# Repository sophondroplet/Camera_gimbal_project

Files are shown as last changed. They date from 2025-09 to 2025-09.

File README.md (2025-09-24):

## Camera Gimbal Project

This repository contains the mechanical CAD, drawings and embedded firmware for a small 2-axis/3-phase BLDC camera gimbal prototype. The project uses an STM32G431 MCU to read an MPU6050 IMU, an AS5048A-style PWM encoder input for rotor position, and drives a 3-phase BLDC (FOC-style) motor using TIM1 complementary PWM outputs.

Folders
- `CAD_files/` – STEP files and drawings for the 3D printed / machined parts and full assembly.
- `assets/` – photos, renders and PCB images used in documentation.
- `Software/STM32G431CUB6_firmware/` – STM32CubeIDE / Makefile firmware project. Contains HAL drivers, MPU6050 code, motor control and UART interface.
- `Software/UART_music_streamer/` – host-side Python utility (`music_streamer.py`) to convert MIDI files or a test scale to motor frequency/torque commands and stream them to the MCU over serial.

High level behaviour
- The MCU reads orientation (roll/pitch/yaw) from the MPU6050 via I2C using DMA.
- An absolute rotor position source (AS5048A PWM-style duty encoder) is read using TIM input capture on `TIM2`.
- A simple PID computes a torque command to follow the IMU-derived pitch setpoint; torque/d (direct/quadrature frame) are converted to 3-phase PWM using inverse Park/Clarke then written to `TIM1` CCR registers.
- UART is used for tuning PID gains at runtime by sending ASCII `P,D\n` lines (see firmware README). Additionally, the host audio streamer sends `FREQ/AMP` lines to play music on the motor (see `Software/UART_music_streamer/README.md`).

Quick start (recommended)
1. Install STM32CubeIDE (recommended) and the STM32G4 device support package.
2. Open the firmware project: `Software/STM32G431CUB6_firmware/gorgon test.ioc` or open the project workspace in STM32CubeIDE.
3. Build the project (Project → Build). Connect an ST-Link and flash using the IDE or STM32CubeProgrammer.

Command-line build & flash (advanced)
- This project contains generated makefiles in the `Debug/` folder. You can build with an ARM GNU toolchain (arm-none-eabi + make). Example (PowerShell):

```powershell
cd .\Software\STM32G431CUB6_firmware\Debug
make all
```

- For flashing, use STM32CubeProgrammer (GUI) or the CLI: point it at the produced ELF/BIN in `Debug/`.

UART protocols in this repo
- PID tuning: send ASCII `P,D\n` lines (example `0.5,0.01\n`) — original firmware parsing behaviour.
- Motor audio streaming: `music_streamer.py` sends `FREQ:<Hz>,AMP:<0..1>\n` lines (example `FREQ:440.00,AMP:0.150\n`). The firmware must be updated to accept `FREQ/AMP` lines or a host proxy must translate them.

Safety and notes
- This firmware drives a BLDC motor. Only connect power and the motor after you have verified wiring and the gate driver. Use low gain values for initial tests and keep motor disconnected while verifying encoder/IMU readings.
- The firmware contains HAL drivers (STM32 HAL and CMSIS). See `Software/STM32G431CUB6_firmware/Drivers/` for license files (Apache/BSD as appropriate).

Resources and where to look next
- Firmware source: `Software/STM32G431CUB6_firmware/Core/Src` and `Core/Inc`.
- IMU code: `MPU6050.c`, `MPU6050_D.c` and headers.
- Motor/FOC code & PID: `main.c`, `music.c`, and the BLDC conversion helpers.
- Host audio streamer: `Software/UART_music_streamer/music_streamer.py` and this folder's README.

If you want, I can also:
- Add the small MCU-side parser for `FREQ/AMP` and a conservative mapping to `TIM6` prescaler or `torque` so `music_streamer.py` works out-of-the-box.
- Populate inline documentation in key source files or add a LICENSE and CONTRIBUTING guide.

License
- The repository contains third-party code (STM32Cube HAL, CMSIS) under their respective license texts included in `Software/STM32G431CUB6_firmware/Drivers/`. The project code inside `Core/` is provided AS-IS unless you tell me otherwise; add or edit a LICENSE file if you want an explicit project license.

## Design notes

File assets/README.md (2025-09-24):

Assets (images)
================

This folder contains photos and renders of the camera gimbal and PCB images used in documentation and presentations. Filenames are prefixed with `cag` and include photos of the build, PCB layouts and CAD screenshots.

Typical use
- Use these images in the main README or in reports/presentations.
- High-resolution images can be opened in any image viewer. Some files are PNG (CAD renders), others are JPG (photos).

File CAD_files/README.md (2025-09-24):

CAD files and drawings
======================

This folder contains STEP (3D CAD) files and drawings for the camera gimbal assembly.

Contents
- `3d_model/` — STEP files for each major part (connectors, top motor jig, TPU vibration damp rubber, and the full assembly). These can be opened in CAD tools such as FreeCAD, Fusion360 or SolidWorks.
- `drawings/Camera_gimbal_drawing.pdf` — a printable drawing with dimensions and assembly notes.

Usage
- Open STEP files in your preferred CAD package. For FreeCAD, use File → Open and select `.step` files. For Fusion360, import the STEP.
- Use `Camera_gimbal_drawing.pdf` for measurements, mounting hole locations and BOM references.

Notes
- STEP files may contain multiple solids and named parts. Export single-part STLs if you need to 3D print components.

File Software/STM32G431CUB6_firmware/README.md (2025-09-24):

STM32G431CUB6 Firmware
======================

This folder contains an STM32CubeIDE project (Gorgon test) which implements motor control and IMU-based stabilization for the camera gimbal prototype. The project targets an STM32G431CBU6 microcontroller and uses HAL drivers with some custom code for the MPU6050 and motor output.

What it implements
- MPU6050 IMU driver (I2C, DMA read) with simple complementary filter fusion (see `Core/Src/MPU6050.c` and `MPU6050_D.c`).
- PWM encoder reading using TIM2 input capture to measure duty cycle and derive absolute rotor angle (used like an AS5048A PWM output).
- Simple PID controller on pitch/angle that computes a torque command which is converted to 3-phase PWM values using inverse Park/Clarke (`main.c`).
- UART-based live PID tuning via ASCII `P,D\n` commands (existing behaviour).
- Optional host-driven audio: the host `music_streamer.py` can stream `FREQ/AMP` commands to the MCU to play music on the motor (see `Software/UART_music_streamer/` README for host-side details). The firmware must accept `FREQ:...,AMP:...` lines or you must add a small parser to convert these commands into internal variables.
- Small music/tone generator that toggles torque with `TIM6` to play notes (see `Core/Inc/music.h` and `Core/Src/music.c`).

Wiring (conceptual)
- Power: motor driver/gate driver and MCU power rails. Ensure correct supply voltages and common grounds.
- TIM1 PWM outputs (CH1/CH2/CH3 and complementary pins) go to the motor driver inputs. Confirm pin mapping in `mx` generated init code.
- TIM2 CH1 (rising capture) and CH2 (falling capture) read the PWM-encoded rotor position (device that outputs PWM duty proportional to angle, typically AS5048A in PWM mode).
- MPU6050: I2C SDA/SCL to `I2C1` pins, interrupt pin to `IMU_INT` GPIO (used to detect data ready). Pull-ups as required.
- UART: USART2 TX/RX used for debug and PID tuning. Connect to USB-serial or ST-Link VCP.

Build & flash
- Recommended: Open the project in STM32CubeIDE (the `.ioc` file is in the folder) and use the IDE to build/flash.
- Command-line: there are makefiles in `Debug/`. Use an ARM GCC toolchain compatible with the flags in the makefile (arm-none-eabi-gcc, make). Example (PowerShell):

```powershell
cd .\Software\STM32G431CUB6_firmware\Debug
make all
```

- The resulting ELF/BIN will be under `Debug/` and can be flashed with STM32CubeProgrammer or the IDE.

Runtime / Tuning
- By default the firmware listens on USART2 for ASCII lines ending in `\n`.
- Send `P,D\n` where `P` and `D` are floating point numbers (no spaces required). Example: `0.5,0.02\n`.
- The firmware echoes the received string and updates the running P and D gains immediately.
- To support `music_streamer.py` you can add a small `FREQ/AMP` parser (see the UART_music_streamer README for a suggested parsing approach). The parsed frequency and amplitude should be safely clamped in firmware before use.

Calibration and safety checklist
- Start with motors disconnected or use a bench load.
- Verify IMU readings first: with motor power off, observe UART debug prints (if enabled) for pitch/roll/yaw values.
- Verify encoder input: check TIM capture values and derived `angle` (look for a 0..2*pi range mapping).
- Use small `P` gains initially and confirm the movement direction is correct.
- Implement emergency stop or physical kill switch before powering motors under load.

Files of interest
- `Core/Inc` – headers for project variables and constants.
- `Core/Src/main.c` – main loop, PID and motor output conversions.
- `Core/Src/MPU6050.c`, `MPU6050_D.c` – IMU drivers.
- `Core/Inc/music.h`, `Core/Src/music.c` – simple tone generator used for debugging.

Licenses
- STM32 HAL and CMSIS code under their included licenses (see `Drivers/`).

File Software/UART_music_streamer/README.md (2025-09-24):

UART Music Streamer
===================

This folder contains `music_streamer.py`, a host-side utility that converts MIDI files (or simple test scales) into realtime motor frequency/torque commands and streams them to the STM32 firmware over a serial link.

What the script does
- Parses MIDI files using `mido` and converts note_on/note_off events into a time-series of (frequency, amplitude) samples.
- Streams those samples at a configurable sample rate to the MCU using an ASCII protocol: `FREQ:<frequency>,AMP:<amplitude>\n` (example: `FREQ:440.00,AMP:0.150\n`).
- Provides a `--scale` test mode to play a C major scale for quick hardware verification.

Dependencies
- Python 3.8+
- pyserial
- mido
- numpy

Install (Windows PowerShell example):

```powershell
python -m pip install --user pyserial mido numpy
```

Usage
- Play a MIDI file over serial:

```powershell
python .\music_streamer.py --port COM3 --baud 115200 path\to\file.mid
```

- Play a test scale:

```powershell
python .\music_streamer.py --port COM3 --baud 115200 --scale
```

Serial protocol emitted by the script
- ASCII line per sample terminated with `\n`.
- Format: `FREQ:<frequency_Hz>,AMP:<amplitude_0_to_1>\n`
- Example: `FREQ:440.00,AMP:0.150\n`

Compatibility and firmware notes
- The `music_streamer.py` script sends `FREQ/AMP` command lines. The firmware in `Software/STM32G431CUB6_firmware` originally parsed `P,D\n` for PID tuning. To use `music_streamer.py` directly you must run firmware that accepts `FREQ/AMP` lines or add a small firmware parser that maps frequency/amplitude to the motor control variables.

Suggested minimal firmware parsing approach
1) Add globals to share the host command (example in a new header `Core/Inc/music_cmd.h`):

```c
// Example globals
extern float host_command_frequency_hz; // Hz
extern float host_command_amplitude;    // 0..1
extern volatile uint8_t host_command_new; // flag set when new command arrives
```

2) In your UART handler (or a small command processing task) parse `FREQ:` lines. Example pseudocode for a simple parser:

```c
void process_serial_line(char *line){
    float f = 0.0f, a = 0.0f;
    if (sscanf(line, "FREQ:%f,AMP:%f", &f, &a) == 2){
        if (f < 0.0f) f = 0.0f;
        if (a < 0.0f) a = 0.0f;
        if (a > 1.0f) a = 1.0f;

        host_command_frequency_hz = f;
        host_command_amplitude = a;
        host_command_new = 1;
    }
}
```

3) Consume `host_command_new` in a safe, periodic context and map frequency to a timer prescaler or to a torque variable. Be conservative with amplitude and frequency limits when driving a motor.

Safety
- The script includes host-side frequency/amplitude constraints, but you should also enforce safe limits in firmware and test with the motor disconnected first.

If you want, I can add the small MCU-side parser and a safe mapping from frequency to `TIM6` prescaler or torque variable — say the word and I will implement it.

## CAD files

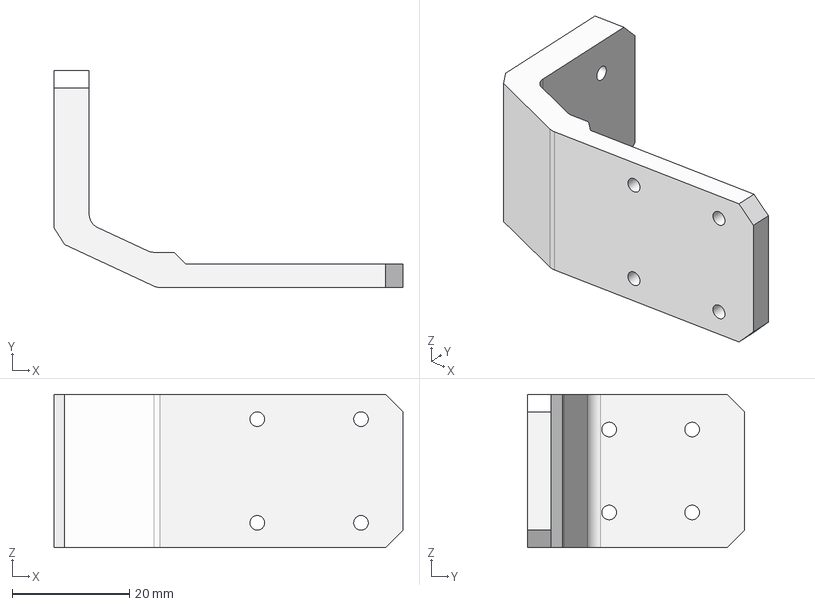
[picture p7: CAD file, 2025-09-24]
CAD_files/3d_model/Main - Roll_pitch_connector.step
59.5 x 37.0 x 26.1 mm

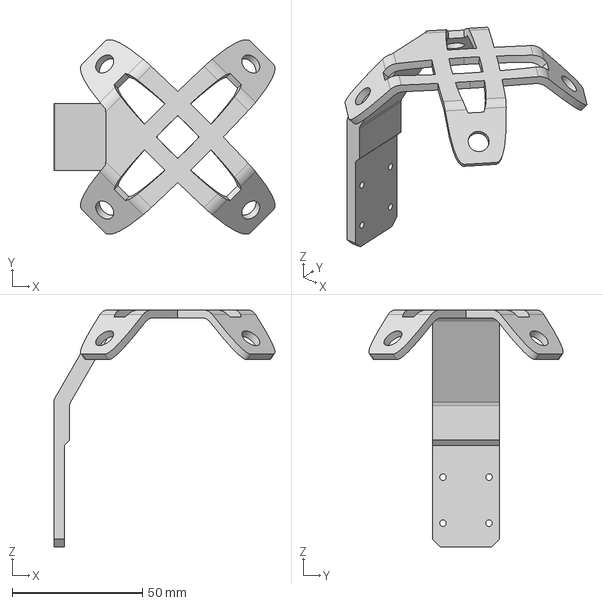
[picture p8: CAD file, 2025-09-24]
CAD_files/3d_model/Main - Roll_connector.step
84.8 x 74.7 x 91.0 mm

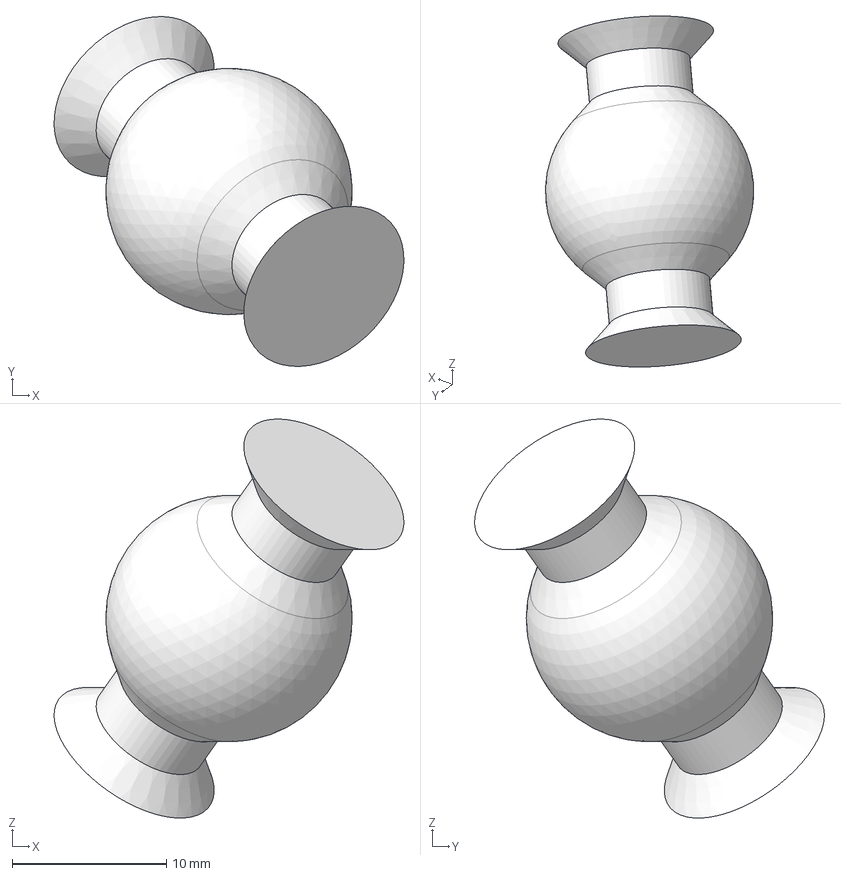
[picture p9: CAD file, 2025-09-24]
CAD_files/3d_model/Main - TPU_vibration_damp_rubber1.step
22.7 x 22.7 x 25.9 mm

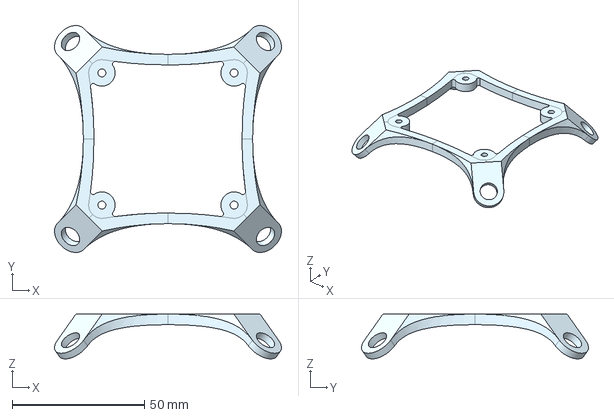
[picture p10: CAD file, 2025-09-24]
CAD_files/3d_model/Main - Top_motor_jig.step
85.8 x 85.8 x 16.9 mm

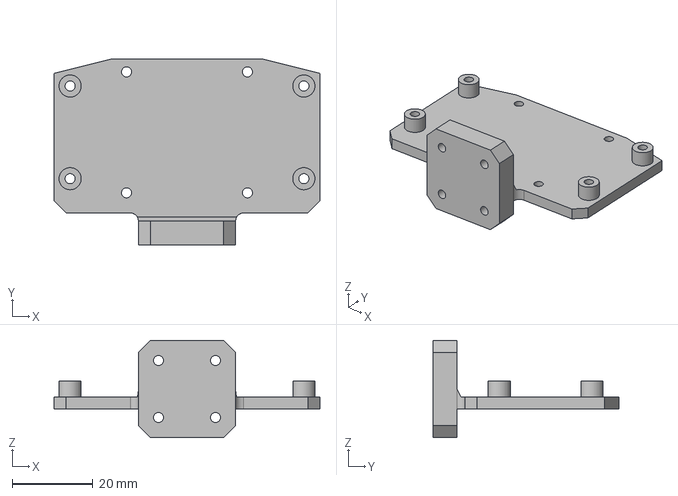
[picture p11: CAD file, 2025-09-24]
CAD_files/3d_model/Main - Pitch_connector.step
66.0 x 46.2 x 24.1 mm

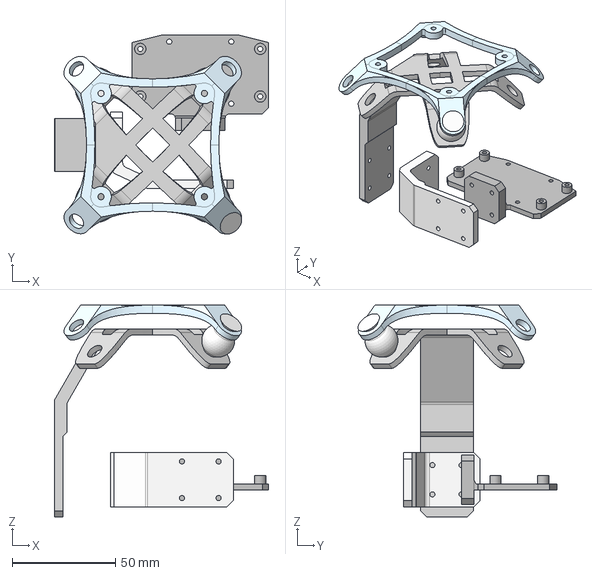
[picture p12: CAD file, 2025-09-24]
CAD_files/3d_model/Main.step
103.5 x 96.3 x 102.5 mm

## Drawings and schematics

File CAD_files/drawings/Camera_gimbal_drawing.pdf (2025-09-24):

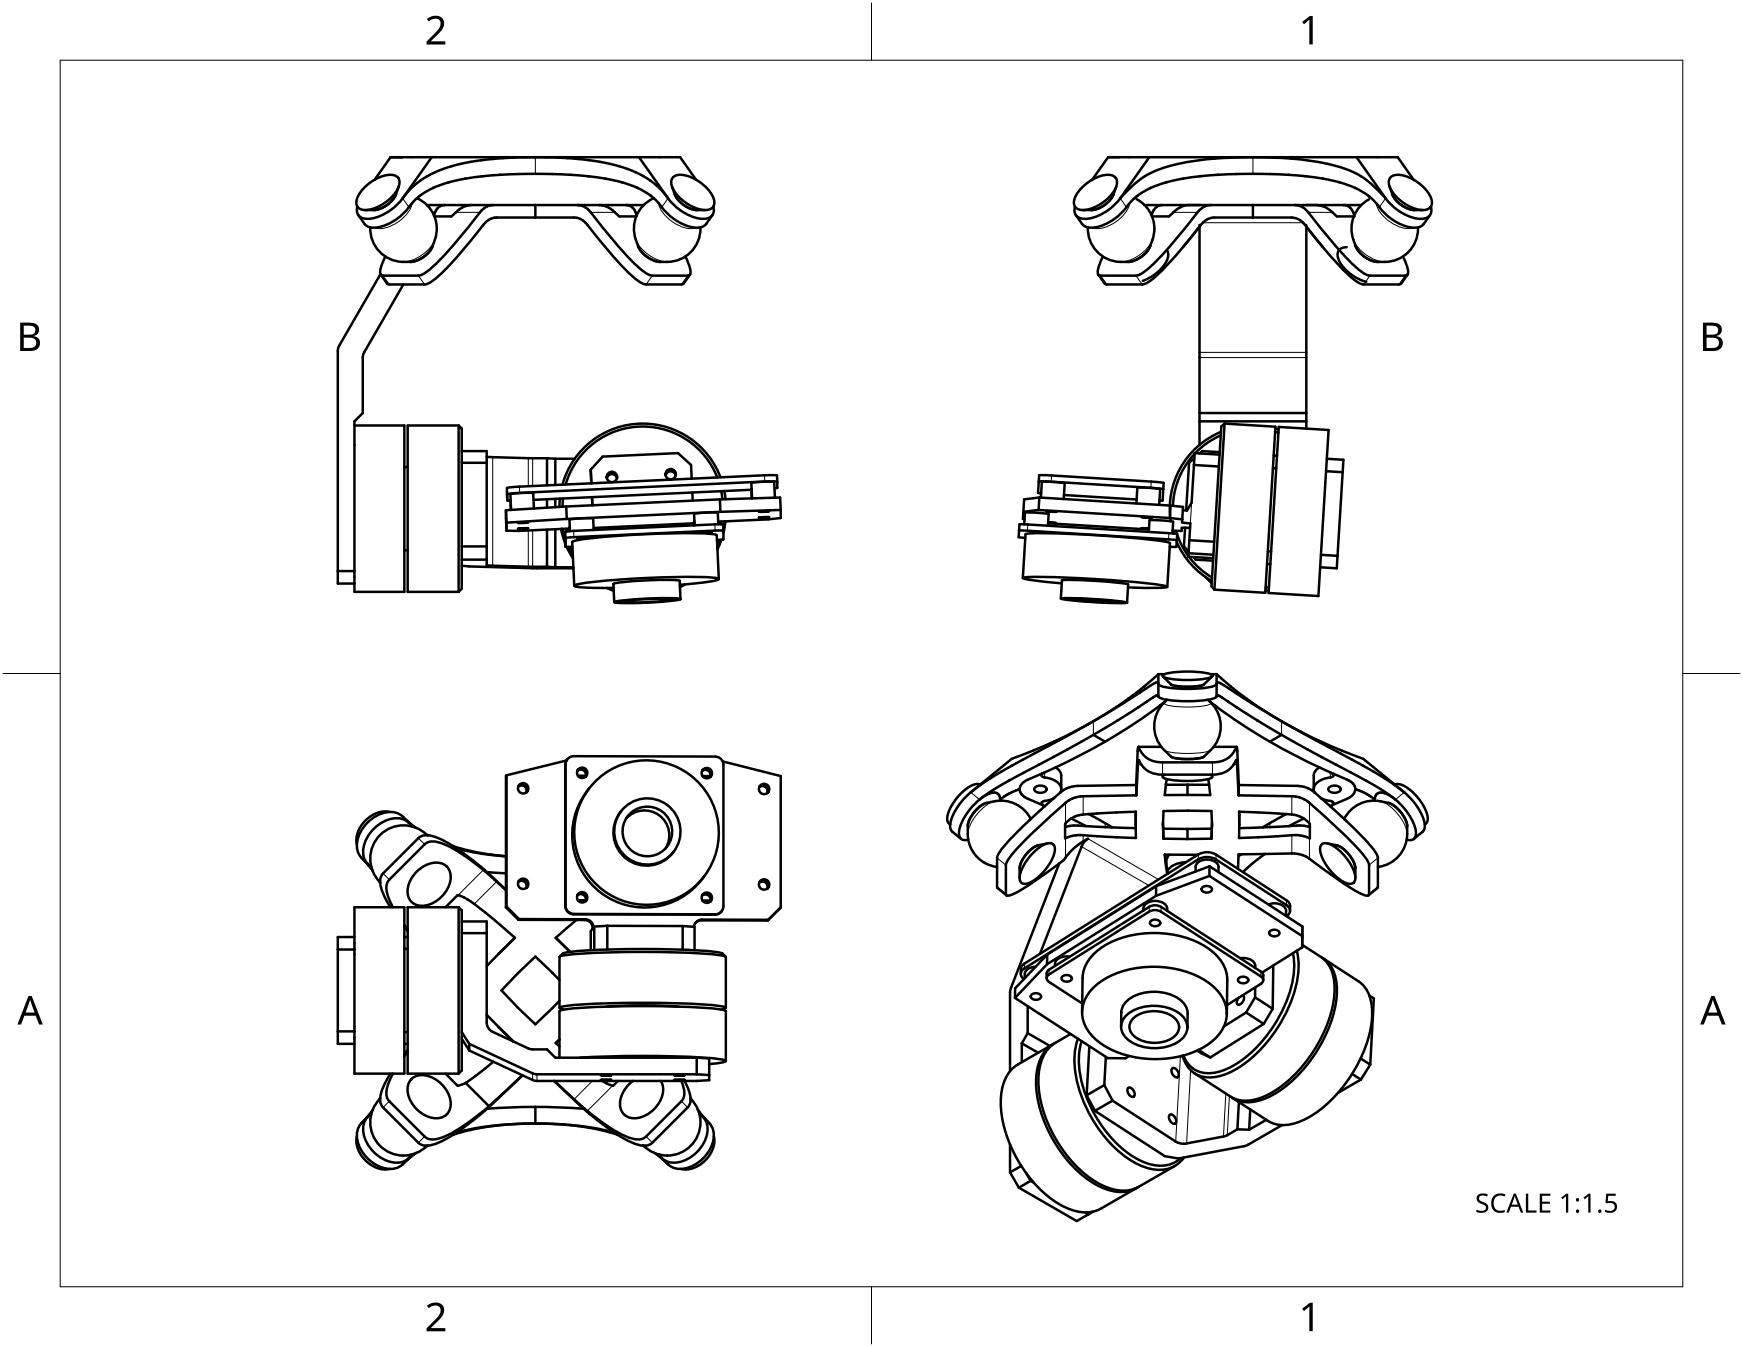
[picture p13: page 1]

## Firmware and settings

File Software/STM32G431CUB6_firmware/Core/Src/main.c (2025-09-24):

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
/* Includes ------------------------------------------------------------------*/
#include "main.h"

/* USER CODE BEGIN Includes */
#include <string.h>
#include <stdio.h>
#include <math.h>
#include <stdlib.h>
#include "music.h"
#include "MPU6050.h"
#include "MPU6050_D.h"
#include "music.h"
/* USER CODE END Includes */

/* USER CODE BEGIN PD */
#define POLE_PAIRS 11
//emprically determined eletrical angle offset
#define EAU 4.137f

#define AS5048A_DUTY_OFFSET 	0.00388443797038f
#define AS5048A_DUTY_GAIN		1.00586080586f

/* USER CODE END PD */

ADC_HandleTypeDef hadc1;
DMA_HandleTypeDef hdma_adc1;

I2C_HandleTypeDef hi2c1;
DMA_HandleTypeDef hdma_i2c1_rx;
DMA_HandleTypeDef hdma_i2c1_tx;

TIM_HandleTypeDef htim1;
TIM_HandleTypeDef htim2;
TIM_HandleTypeDef htim6;
TIM_HandleTypeDef htim7;

UART_HandleTypeDef huart2;
DMA_HandleTypeDef hdma_usart2_rx;

/* USER CODE BEGIN PV */

// PWM input (encoder variables)
uint32_t frequency;
uint32_t period;
float dutycycle;
uint32_t hightime;
float angle;
volatile float angle_setpoint;

//UART serial debug variables
int count_test;
char buffer[250];
uint8_t indx;
uint8_t UART_rx_byte;
uint8_t UART_rx_buffer[30];

HAL_StatusTypeDef stat;

//ADC potentiometer variables
volatile uint32_t potVal;

//Motor driving variables
volatile float torque; //rotor quadrature
float d; //rotor direct
float angletest;
float angletestrad;

float a;
float b;
float c;

uint16_t counter_period;

//flags
uint8_t ADC_flag;
uint8_t IMU_flag;

//PID loop variables
volatile uint32_t prev_tick = 0;  // Previous tick count (HAL_GetTick)
volatile uint32_t prev_val = 0;
volatile prev_dt;// Previous SysTick->VAL
volatile float Curr_error;

volatile float P;
//static float I;
volatile float D;


float dt = 0.0000625f;

MPU6050 mpu;

/* USER CODE END PV */

void SystemClock_Config(void);
static void MX_GPIO_Init(void);
static void MX_DMA_Init(void);
static void MX_TIM2_Init(void);
static void MX_USART2_UART_Init(void);
static void MX_I2C1_Init(void);
static void MX_TIM1_Init(void);
static void MX_ADC1_Init(void);
static void MX_TIM6_Init(void);
static void MX_TIM7_Init(void);
/* USER CODE BEGIN 0 */

//Motor driver stuff

void print(char *msg);

void BLDC_TorquetoPWM(float theta){

	float x;
	float y;

	//convert from electrical angle to mechanical angle
	theta = theta * POLE_PAIRS - EAU;
	//Inverse park transform
	x = d*cosf(theta) - torque*sinf(theta);
	y = d*sinf(theta) + torque*cosf(theta);

	//Inverse clarke transform
	a = x;
	b = -1.0*x/2.0 + y*M_SQRT3_OVER_2;
	c = -1.0*x/2.0 - y*M_SQRT3_OVER_2;

	counter_period = __HAL_TIM_GET_AUTORELOAD(&htim1);

	TIM1->CCR1 = ((a/2)+0.5)* counter_period;
	TIM1->CCR2 = ((b/2)+0.5)* counter_period;
	TIM1->CCR3 = ((c/2)+0.5)* counter_period;

//	sprintf(buffer, "%lu, %lu, %lu\r\n", TIM1->CCR1, TIM1->CCR2, TIM1->CCR3);
//	print(buffer);
}



/* I2C stuff */

//reading PWM signal


//Serial
void print(char *msg){
	HAL_UART_Transmit(&huart2, (uint8_t*)buffer, strlen(buffer),100);
}

void init_time(){
    prev_tick = HAL_GetTick();  // Get current millisecond count
    prev_val = SysTick->VAL;    // Get SysTick counter value
}

void count(){
	count_test += 1;
}

int32_t PID(){

	static float Prev_error;
	//	static float integral;
	float derivative;

	//Calculate error, with direction
	if ((angle_setpoint - angle) > 0){
		if ((angle_setpoint - angle)> M_PI){
			Curr_error = (2*M_PI - (angle_setpoint - angle));
		}else{
			Curr_error = -(angle_setpoint - angle);
		}

	}else{
		if ((angle_setpoint - angle)< -M_PI){
			Curr_error = -(2*M_PI + (angle_setpoint - angle));
		}else{
			Curr_error = -(angle_setpoint - angle);
		}
	}

	derivative = (Curr_error-Prev_error)/dt;

//	integral += Curr_error*dt;
//	if (Curr_error >= 0.01 | Curr_error <= -0.01 ){

	torque = P*Curr_error;

//	}else{
//
//		torque = 0;
//
//	}

	torque = fmaxf(fminf(torque,0.25),-0.25);


//	sprintf(buffer, "%d\r\n", (int)(Curr_error*100000));
//	print(buffer);


//	prev_dt = dt;
}

//Callbacks

void HAL_TIM_PeriodElapsedCallback(TIM_HandleTypeDef *htim){
	if (htim->Instance == TIM7){
//		play_music(&htim6);
		PID();
		BLDC_TorquetoPWM(angle);
//		angle_setpoint = fmaxf(fminf((potVal/ 4096.0f)*2 *M_PI, 2 *M_PI),0);
		angle_setpoint = pitch;
	}
}



void HAL_TIM_IC_CaptureCallback(TIM_HandleTypeDef *htim){
//Update value once every period
	if (htim->Channel == HAL_TIM_ACTIVE_CHANNEL_1){
		period = HAL_TIM_ReadCapturedValue(htim, TIM_CHANNEL_1);
		hightime = HAL_TIM_ReadCapturedValue(htim, TIM_CHANNEL_2);
		if(period != 0){
			//channel 1 only capture rising edges
			//Channel 1 returns ticks elapsed between 2 rising edges
			//channel 2 captures both rising and fallign edges
			//Channel 2 returns ticks elapsed between a rising and falling edge
			//Both timers reset each rising edge in PWM input mode

			dutycycle = (float)hightime/(float)period;
			dutycycle -= AS5048A_DUTY_OFFSET;
			dutycycle *= AS5048A_DUTY_GAIN;

			uint16_t rotor_position_bits = (uint16_t)(dutycycle * 4095.0f + 0.5f);
			angle = (float)rotor_position_bits * 2.0f * M_PI / 4096.0f;

//			sprintf(buffer, "%lu\r\n", (uint32_t)(angle*100000));
//			print(buffer);
		}
	}
}
void HAL_I2C_MemRxCpltCallback(I2C_HandleTypeDef *hi2c){
	mpu.gotData = 1;
	rx_flag = 0;
}

//void HAL_ADC_ConvCpltCallback(ADC_HandleTypeDef *hadc) {
////	HAL_ADC_Start_DMA(&hadc1, &potVal, 1);
//}

void HAL_UART_RxCpltCallback(UART_HandleTypeDef *huart) {
    if (huart->Instance == USART2) {
        if (UART_rx_byte == '\n') {
            // Trim trailing \r if present
            if (indx > 0 && UART_rx_buffer[indx-1] == '\r') {
                UART_rx_buffer[indx-1] = '\0';
            } else {
                UART_rx_buffer[indx] = '\0';
            }

            HAL_UART_Transmit(&huart2, (uint8_t*)UART_rx_buffer, indx, 100);

            char *comma = strchr(UART_rx_buffer, ',');
            if (comma != NULL) {
                *comma = '\0';
                char *endptr;

                // Parse P
                P = strtof(UART_rx_buffer, &endptr);
                if (endptr == UART_rx_buffer) {
                    // Error: Invalid P
                    P = 0.0f;
                }

                // Parse D
                D = strtof(comma + 1, &endptr);
                if (endptr == comma + 1) {
                    // Error: Invalid D
                    D = 0.0f;
                }
            } else {
                P = 0.0f;
                D = 0.0f;
            }

            memset(UART_rx_buffer, 0, 30);
            indx = 0;
        } else {
            if (indx < 29) {
                UART_rx_buffer[indx] = UART_rx_byte;
                indx++;
            } else {
                indx = 0; // Reset on overflow
            }
        }
        HAL_UART_Receive_IT(&huart2, &UART_rx_byte, 1);
    }
}

/* USER CODE END 0 */

/**
  * @brief  The application entry point.
  * @retval int
  */
int main(void)
{

  /* MCU Configuration--------------------------------------------------------*/

  /* Reset of all peripherals, Initializes the Flash interface and the Systick. */
  HAL_Init();

  /* Configure the system clock */
  SystemClock_Config();

  /* Initialize all configured peripherals */
  MX_GPIO_Init();
  MX_DMA_Init();
  MX_TIM2_Init();
  MX_USART2_UART_Init();
  MX_I2C1_Init();
  MX_TIM1_Init();
  MX_ADC1_Init();
  MX_TIM6_Init();
  MX_TIM7_Init();
  /* USER CODE BEGIN 2 */
  torque = 0;
  d = 0;

  P = 0.5;
  D = 0;

  MPU6050_init(&hi2c1);
  MPU6050_Initialize(&mpu, &hi2c1);
//  MPU6050_Read_DMA(&mpu);
//  MPU6050_read_poll_data(&hi2c1);
  HAL_UART_Receive_IT(&huart2,&UART_rx_byte, 1);
//  HAL_ADC_Start_DMA(&hadc1,(uint32_t*)&potVal, 1);

  /* USER CODE END 2 */

  /* Infinite loop */
  /* USER CODE BEGIN WHILE */
  while (1)
 {
//	  sprintf(buffer, "main loop running\r\n");
//	  print(buffer);


	  mpu.newData = HAL_GPIO_ReadPin(IMU_INT_GPIO_Port, IMU_INT_Pin);

	  if (mpu.newData == 1 && rx_flag == 0){
		  MPU6050_read_DMA_data(&hi2c1);
//		  MPU6050_Read_DMA(&mpu);
	  }

	  if (mpu.gotData == 1){
		  MPU6050_process_data();
//		  MPU6050_Process_DMA_Data(&mpu);
		  mpu.gotData = 0;

//		  sprintf(buffer, "%f, %f, %f \r\n", roll*(180/M_PI),pitch*(180/M_PI),yaw*(180/M_PI));
//		  print(buffer);
	  }

    /* USER CODE END WHILE */

    /* USER CODE BEGIN 3 */
  }
  /* USER CODE END 3 */
}

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


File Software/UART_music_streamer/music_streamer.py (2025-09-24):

#!/usr/bin/env python3
"""
MIDI to BLDC Motor Audio Player
Converts MIDI files to frequency commands for STM32 FOC motor control
Sends real-time audio data via UART to play music on brushless motor
"""

import serial
import mido
import time
import numpy as np
from threading import Thread, Lock
from collections import deque
import argparse
import sys

class MIDIToMotorPlayer:
    def __init__(self, port='/dev/ttyUSB0', baudrate=115200, sample_rate=1000):
        self.serial_port = port
        self.baudrate = baudrate
        self.sample_rate = sample_rate  # Hz
        self.sample_interval = 1.0 / sample_rate
        
        # Motor parameters
        self.min_frequency = 20  # Hz - minimum audible frequency
        self.max_frequency = 5000  # Hz - maximum safe motor frequency
        self.base_amplitude = 0.3  # Base torque modulation amplitude
        
        # Audio state
        self.current_notes = {}  # Active notes: {note_number: (frequency, velocity, start_time)}
        self.playing = False
        self.serial_conn = None
        self.playback_thread = None
        self.audio_buffer = deque(maxlen=1000)
        self.buffer_lock = Lock()
        
        # MIDI note to frequency conversion (A4 = 440Hz)
        self.midi_reference = 69  # A4 MIDI note number
        self.a4_frequency = 440.0
        
    def midi_to_frequency(self, note_number):
        """Convert MIDI note number to frequency in Hz"""
        return self.a4_frequency * (2 ** ((note_number - self.midi_reference) / 12.0))
    
    def frequency_to_torque(self, frequency, amplitude=1.0):
        """Convert frequency to motor torque command"""
        # Normalize frequency to safe motor operating range
        if frequency < self.min_frequency:
            return 0.0
        
        # Scale amplitude based on frequency (prevent high-frequency damage)
        safe_amplitude = amplitude * min(1.0, 2000.0 / frequency)
        
        return safe_amplitude * self.base_amplitude
    
    def connect_serial(self):
        """Establish serial connection to STM32"""
        try:
            self.serial_conn = serial.Serial(
                port=self.serial_port,
                baudrate=self.baudrate,
                parity=serial.PARITY_NONE,
                stopbits=serial.STOPBITS_ONE,
                bytesize=serial.EIGHTBITS,
                timeout=1
            )
            print(f"Connected to {self.serial_port} at {self.baudrate} baud")
            return True
        except serial.SerialException as e:
            print(f"Serial connection error: {e}")
            return False
    
    def send_motor_command(self, frequency, amplitude):
        """Send frequency command to motor via UART"""
        if not self.serial_conn:
            return False
        
        try:
            # Protocol: "FREQ:xxx.xx,AMP:y.yy\n"
            command = f"FREQ:{frequency:.2f},AMP:{amplitude:.3f}\n"
            self.serial_conn.write(command.encode('utf-8'))
            return True
        except Exception as e:
            print(f"Error sending command: {e}")
            return False
    
    def parse_midi_file(self, midi_file_path):
        """Parse MIDI file and extract note events with timing"""
        try:
            midi_file = mido.MidiFile(midi_file_path)
            events = []
            
            # Calculate ticks per second based on tempo
            ticks_per_beat = midi_file.ticks_per_beat
            default_tempo = 500000  # microseconds per beat (120 BPM)
            
            current_tempo = default_tempo
            absolute_time = 0  # in ticks
            tempo_changes = []
            
            # First pass: collect tempo changes
            for track in midi_file.tracks:
                track_time = 0
                for msg in track:
                    track_time += msg.time
                    if msg.type == 'set_tempo':
                        tempo_changes.append((track_time, msg.tempo))
            
            # Process all tracks
            for track in midi_file.tracks:
                track_time = 0
                
                for msg in track:
                    track_time += msg.time
                    absolute_time = track_time
                    
                    # Update tempo if needed
                    current_tempo = default_tempo
                    for change_time, tempo in tempo_changes:
                        if change_time <= absolute_time:
                            current_tempo = tempo
                    
                    # Convert ticks to seconds
                    ticks_per_second = (1_000_000 / current_tempo) * ticks_per_beat
                    timestamp = absolute_time / ticks_per_second
                    
                    if msg.type == 'note_on' and msg.velocity > 0:
                        frequency = self.midi_to_frequency(msg.note)
                        events.append({
                            'type': 'note_on',
                            'note': msg.note,
                            'frequency': frequency,
                            'velocity': msg.velocity / 127.0,  # Normalize to 0-1
                            'time': timestamp
                        })
                    elif msg.type == 'note_off' or (msg.type == 'note_on' and msg.velocity == 0):
                        events.append({
                            'type': 'note_off',
                            'note': msg.note,
                            'time': timestamp
                        })
            
            # Sort events by time
            events.sort(key=lambda x: x['time'])
            return events
            
        except Exception as e:
            print(f"Error parsing MIDI file: {e}")
            return []
    
    def generate_audio_buffer(self, midi_events, duration):
        """Generate real-time audio buffer from MIDI events"""
        current_time = 0
        event_index = 0
        active_notes = {}
        
        while current_time < duration and event_index < len(midi_events):
            # Process events at current time
            while (event_index < len(midi_events) and (midi_events[event_index]['time'] <= current_time):
                event = midi_events[event_index]
                
                if event['type'] == 'note_on':
                    active_notes[event['note']] = {
                        'frequency': event['frequency'],
                        'amplitude': event['velocity'],
                        'start_time': current_time
                    }
                elif event['type'] == 'note_off' and event['note'] in active_notes:
                    del active_notes[event['note']]
                
                event_index += 1
            
            # Calculate combined signal from active notes (simple additive synthesis)
            if active_notes:
                # For polyphonic music, we can mix multiple frequencies
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

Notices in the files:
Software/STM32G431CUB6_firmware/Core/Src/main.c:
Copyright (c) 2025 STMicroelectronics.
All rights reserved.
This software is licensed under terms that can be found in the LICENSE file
